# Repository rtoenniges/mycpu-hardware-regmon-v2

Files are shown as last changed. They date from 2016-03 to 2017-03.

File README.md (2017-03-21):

# MyCPU_HDW_RegMonV2
A hardware expansion for for the [MyCPU](http://www.mycpu.eu/) from Dennis Kuschel to display the various CPU internal registers.

#### Attention: 
**This project especially the layouts are not yet finished and have _never been tested!_
So be careful if you connect this to your MyCPU!**

## Features
- Values display in Hex using an EPROM to convert Binary to 7-segment
- Hold CPU on a specific address using DIP-Switches
- You dont have to build the whole Monitor - Its split into 3x Driver and 2x Monitor modules

## Registers
- Accu
- X-Reg
- Y-Reg
- Stackpointer
- OP-Code
- ALU-Reg 1
- ALU-Reg 2
- ALU-OUT
- Sign-, Zero-, Carry-Flag
- Program Counter
- Addressregister

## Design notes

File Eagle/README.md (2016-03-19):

# Hardware (Drivers and Monitors)
The hardware is each splitted into two modules (Driver and Monitor).
The two modules where connected by a ribbon cable which should not be too long.

## Driver 1 (Program Counter) -> Monitor 12
Driver 1 is for the Program Counter and have to be placed between the Signal Decoder- and the Program Counter-Board.

You have to remove IC44 and IC46 from the Program-Counter-Board and place it on the Driver 1-Board and use IC socket extensions to connect the ICs again to the Programm Counter-Board like the Memory-Base-, and the Memory-Extension-Board.

You can connect the Monitor 12-Board to display the Programm Counter value.

## Driver 2 (Address Bus) -> Monitor 12, AddressHold
Driver 2 is for the Address Bus and have to be placed between the Program Counter- and the Bus Interface-Board

You can connect the Monitor 12-Board to display the Address Bus value and with the AddressHold-Board you can select an address with dip-switches to hold the CPU on a specific point.

## Driver 3 (Accu, X, Y, SP, OP, AR1, AR2, ALU, O-, V-, C-Flag) -> Monitor 3
Driver 3 is for the various internal CPU register and have to be placed between the Microcode Control- and the Signal Decoder-Board.

You can connect the Monitor 3-Board to display all the registers and flags.

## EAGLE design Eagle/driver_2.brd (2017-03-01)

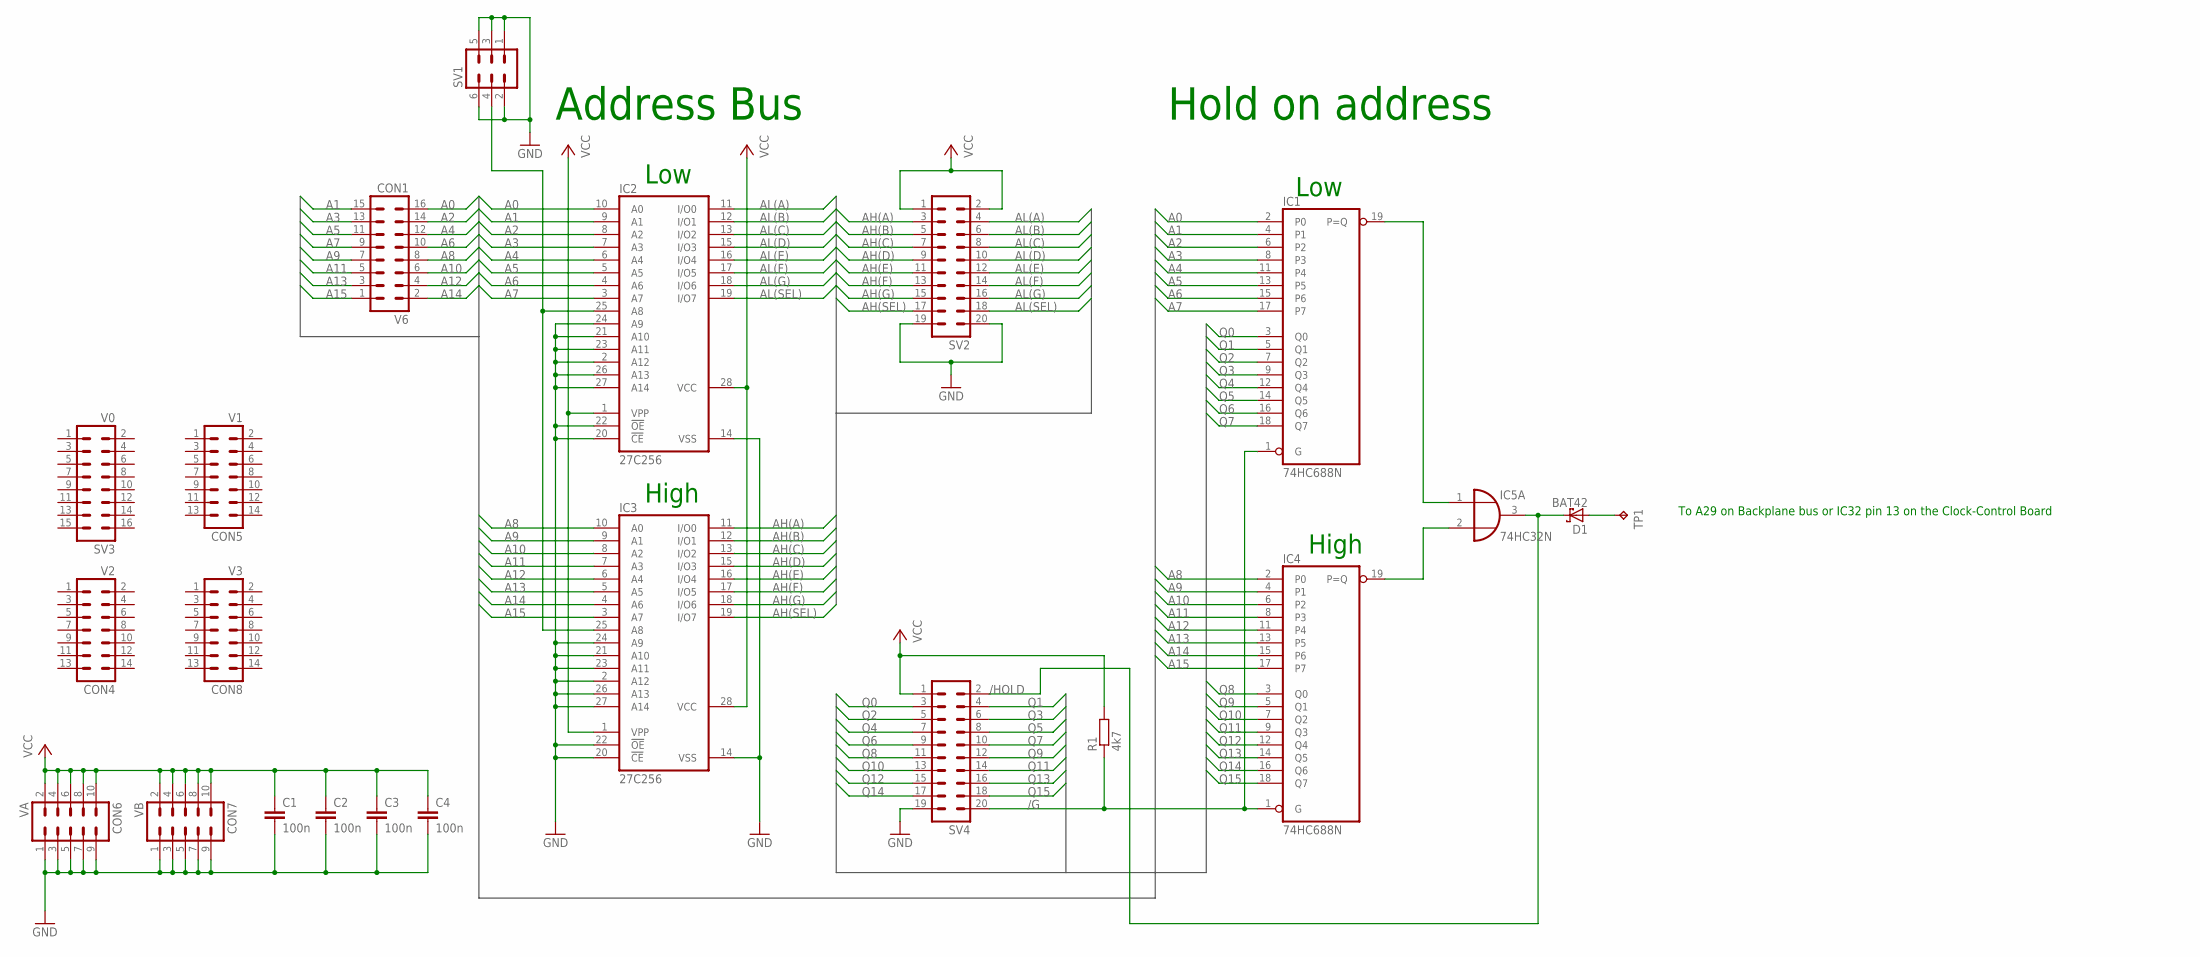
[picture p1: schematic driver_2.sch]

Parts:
C1, C2, C3, C4: 100n; C050-024X044
CON1: V6; ML16
CON4: V2; ML14
CON5: V1; ML14
CON6: VA; ML10
CON7: VB; ML10
CON8: V3; ML14
D1: BAT42; DO35-10
IC1, IC4: 74HC688N; DIL20
IC2, IC3: 27C256; DIL28-6
IC5: 74HC32N; DIL14
R1: 4k7; 0204/5
SV1: ML6
SV2, SV4: ML20L
SV3: V0; ML16
TP1: Interface -> R12; P1-17

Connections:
/G: IC1.1 (G), IC4.1 (G), R1.1, SV4.20
/HOLD: D1.C, IC5.3 (O), SV4.2
A0: CON1.16, IC1.2 (P0), IC2.10 (A0)
A1: CON1.15, IC1.4 (P1), IC2.9 (A1)
A2: CON1.14, IC1.6 (P2), IC2.8 (A2)
A3: CON1.13, IC1.8 (P3), IC2.7 (A3)
A4: CON1.12, IC1.11 (P4), IC2.6 (A4)
A5: CON1.11, IC1.13 (P5), IC2.5 (A5)
A6: CON1.10, IC1.15 (P6), IC2.4 (A6)
A7: CON1.9, IC1.17 (P7), IC2.3 (A7)
A8: CON1.8, IC3.10 (A0), IC4.2 (P0)
A9: CON1.7, IC3.9 (A1), IC4.4 (P1)
A10: CON1.6, IC3.8 (A2), IC4.6 (P2)
A11: CON1.5, IC3.7 (A3), IC4.8 (P3)
A12: CON1.4, IC3.6 (A4), IC4.11 (P4)
A13: CON1.3, IC3.5 (A5), IC4.13 (P5)
A14: CON1.2, IC3.4 (A6), IC4.15 (P6)
A15: CON1.1, IC3.3 (A7), IC4.17 (P7)
AH(A): IC3.11 (I/O0), SV2.3
AH(B): IC3.12 (I/O1), SV2.5
AH(C): IC3.13 (I/O2), SV2.7
AH(D): IC3.15 (I/O3), SV2.9
AH(E): IC3.16 (I/O4), SV2.11
AH(F): IC3.17 (I/O5), SV2.13
AH(G): IC3.18 (I/O6), SV2.15
AH(SEL): IC3.19 (I/O7), SV2.17
AL(A): IC2.11 (I/O0), SV2.4
AL(B): IC2.12 (I/O1), SV2.6
AL(C): IC2.13 (I/O2), SV2.8
AL(D): IC2.15 (I/O3), SV2.10
AL(E): IC2.16 (I/O4), SV2.12
AL(F): IC2.17 (I/O5), SV2.14
AL(G): IC2.18 (I/O6), SV2.16
AL(SEL): IC2.19 (I/O7), SV2.18
GND: C1.2, C2.2, C3.2, C4.2, CON6.1, CON6.3, CON6.5, CON6.7, CON6.9, CON7.1, CON7.3, CON7.5, CON7.7, CON7.9, IC1.10 (GND), IC2.2 (A12), IC2.14 (VSS), IC2.20 (!CE), IC2.21 (A10), IC2.22 (!OE), IC2.23 (A11), IC2.24 (A9), IC2.26 (A13), IC2.27 (A14), IC3.2 (A12), IC3.14 (VSS), IC3.20 (!CE), IC3.21 (A10), IC3.22 (!OE), IC3.23 (A11), IC3.24 (A9), IC3.26 (A13), IC3.27 (A14), IC4.10 (GND), IC5.7 (GND), SV1.1, SV1.2, SV1.3, SV1.5, SV1.6, SV2.19, SV2.20, SV4.19
unnamed: IC2.25 (A8), IC3.25 (A8), SV1.4
unnamed: IC1.19 (P=Q), IC5.1 (I0)
unnamed: IC4.19 (P=Q), IC5.2 (I1)
unnamed: D1.A, TP1.TP
Q0: IC1.3 (Q0), SV4.3
Q1: IC1.5 (Q1), SV4.4
Q2: IC1.7 (Q2), SV4.5
Q3: IC1.9 (Q3), SV4.6
Q4: IC1.12 (Q4), SV4.7
Q5: IC1.14 (Q5), SV4.8
Q6: IC1.16 (Q6), SV4.9
Q7: IC1.18 (Q7), SV4.10
Q8: IC4.3 (Q0), SV4.11
Q9: IC4.5 (Q1), SV4.12
Q10: IC4.7 (Q2), SV4.13
Q11: IC4.9 (Q3), SV4.14
Q12: IC4.12 (Q4), SV4.15
Q13: IC4.14 (Q5), SV4.16
Q14: IC4.16 (Q6), SV4.17
Q15: IC4.18 (Q7), SV4.18
VCC: C1.1, C2.1, C3.1, C4.1, CON6.2, CON6.4, CON6.6, CON6.8, CON6.10, CON7.2, CON7.4, CON7.6, CON7.8, CON7.10, IC1.20 (VCC), IC2.1 (VPP), IC2.28 (VCC), IC3.1 (VPP), IC3.28 (VCC), IC4.20 (VCC), IC5.14 (VCC), R1.2, SV2.1, SV2.2, SV4.1

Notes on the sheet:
Address Bus
Low
High
Hold on address
To A29 on Backplane bus or IC32 pin 13 on the Clock-Control Board

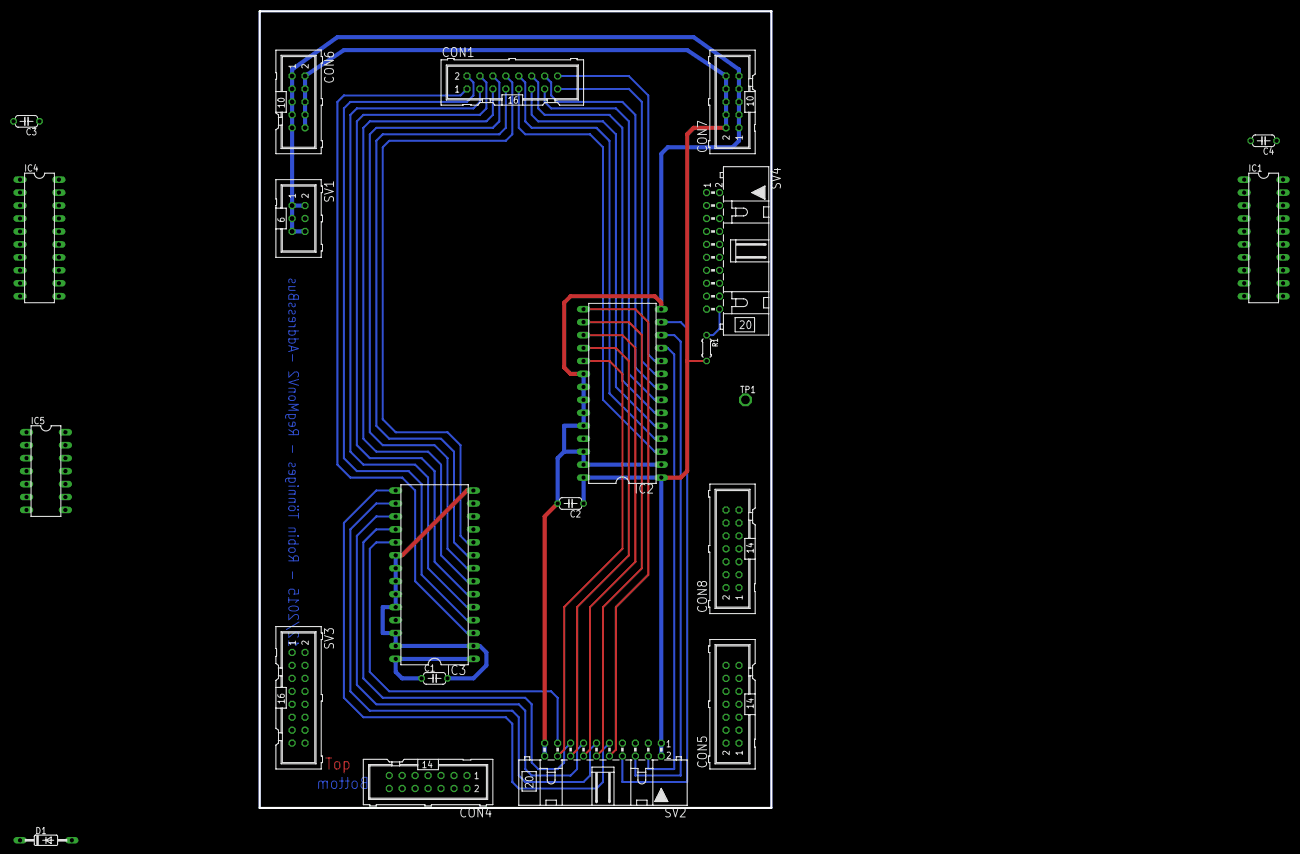
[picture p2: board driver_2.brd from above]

Board: 2 copper layers, 100.3 x 156.2 mm, 22 parts (0 on the bottom side), 56 nets.

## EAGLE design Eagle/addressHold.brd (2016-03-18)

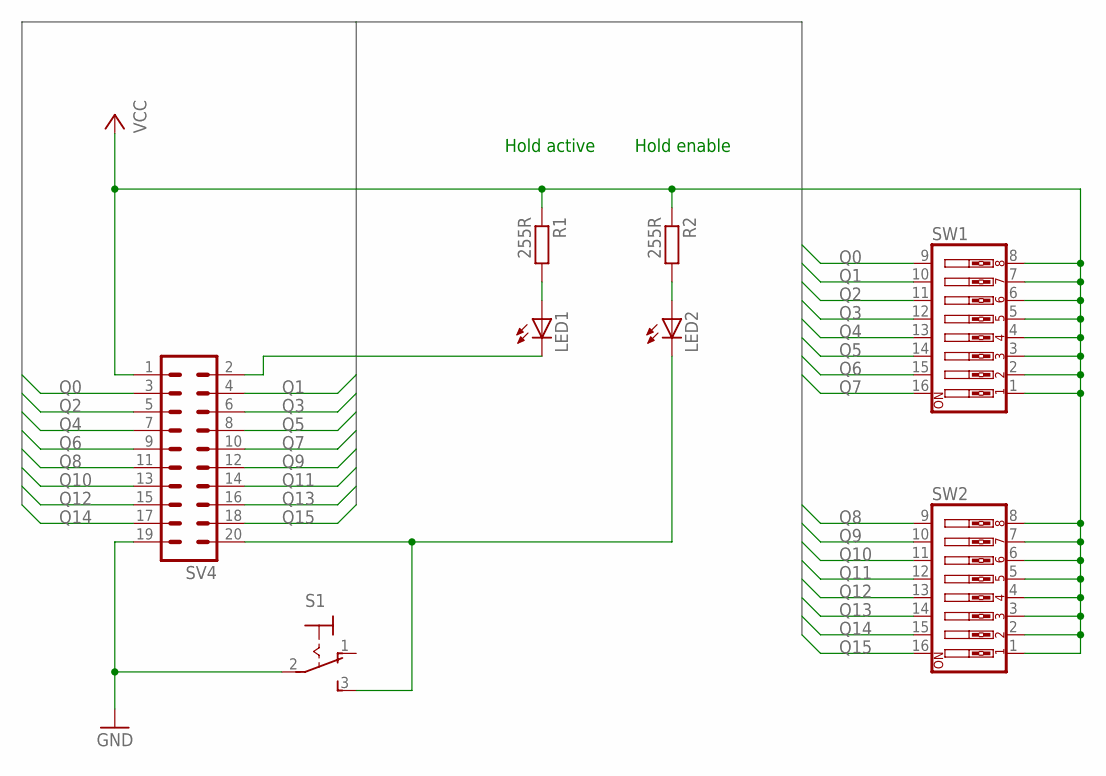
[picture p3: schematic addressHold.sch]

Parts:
LED1, LED2: LED5MM
R1, R2: 255R; 0204/5
S1: 320-916
SV4: ML20L
SW1, SW2: SW_DIP-8; EDG-08

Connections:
GND: S1.2, SV4.19
unnamed: LED2.K (C), S1.3 (S), SV4.20
unnamed: LED1.K (C), SV4.2
unnamed: LED1.A, R1.2
unnamed: LED2.A, R2.2
Q0: SV4.3, SW1.9
Q1: SV4.4, SW1.10
Q2: SV4.5, SW1.11
Q3: SV4.6, SW1.12
Q4: SV4.7, SW1.13
Q5: SV4.8, SW1.14
Q6: SV4.9, SW1.15
Q7: SV4.10, SW1.16
Q8: SV4.11, SW2.9
Q9: SV4.12, SW2.10
Q10: SV4.13, SW2.11
Q11: SV4.14, SW2.12
Q12: SV4.15, SW2.13
Q13: SV4.16, SW2.14
Q14: SV4.17, SW2.15
Q15: SV4.18, SW2.16
VCC: R1.1, R2.1, SV4.1, SW1.1, SW1.2, SW1.3, SW1.4, SW1.5, SW1.6, SW1.7, SW1.8, SW2.1, SW2.2, SW2.3, SW2.4, SW2.5, SW2.6, SW2.7, SW2.8

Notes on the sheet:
Hold enable
Hold active

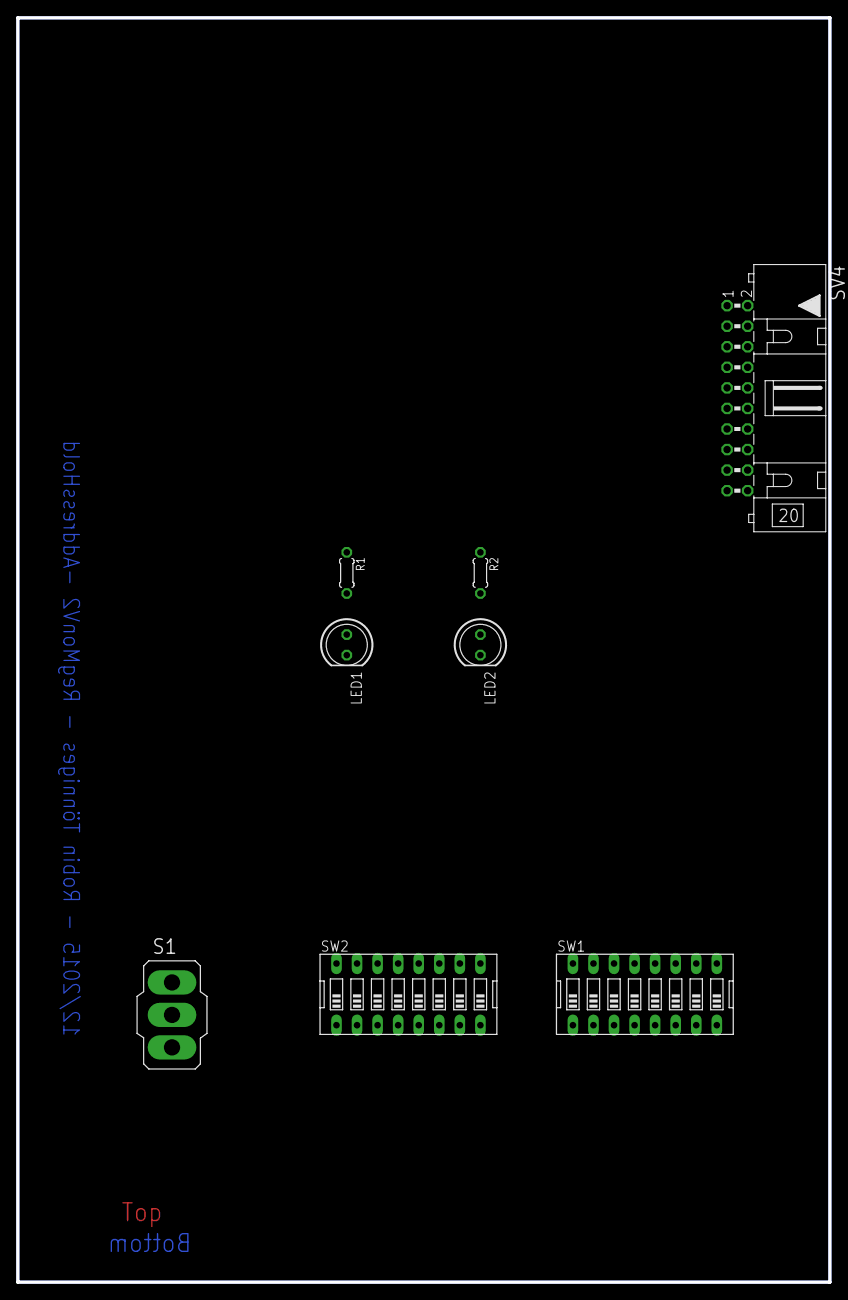
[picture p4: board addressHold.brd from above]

Board: 2 copper layers, 100.3 x 156.2 mm, 8 parts (0 on the bottom side), 22 nets.

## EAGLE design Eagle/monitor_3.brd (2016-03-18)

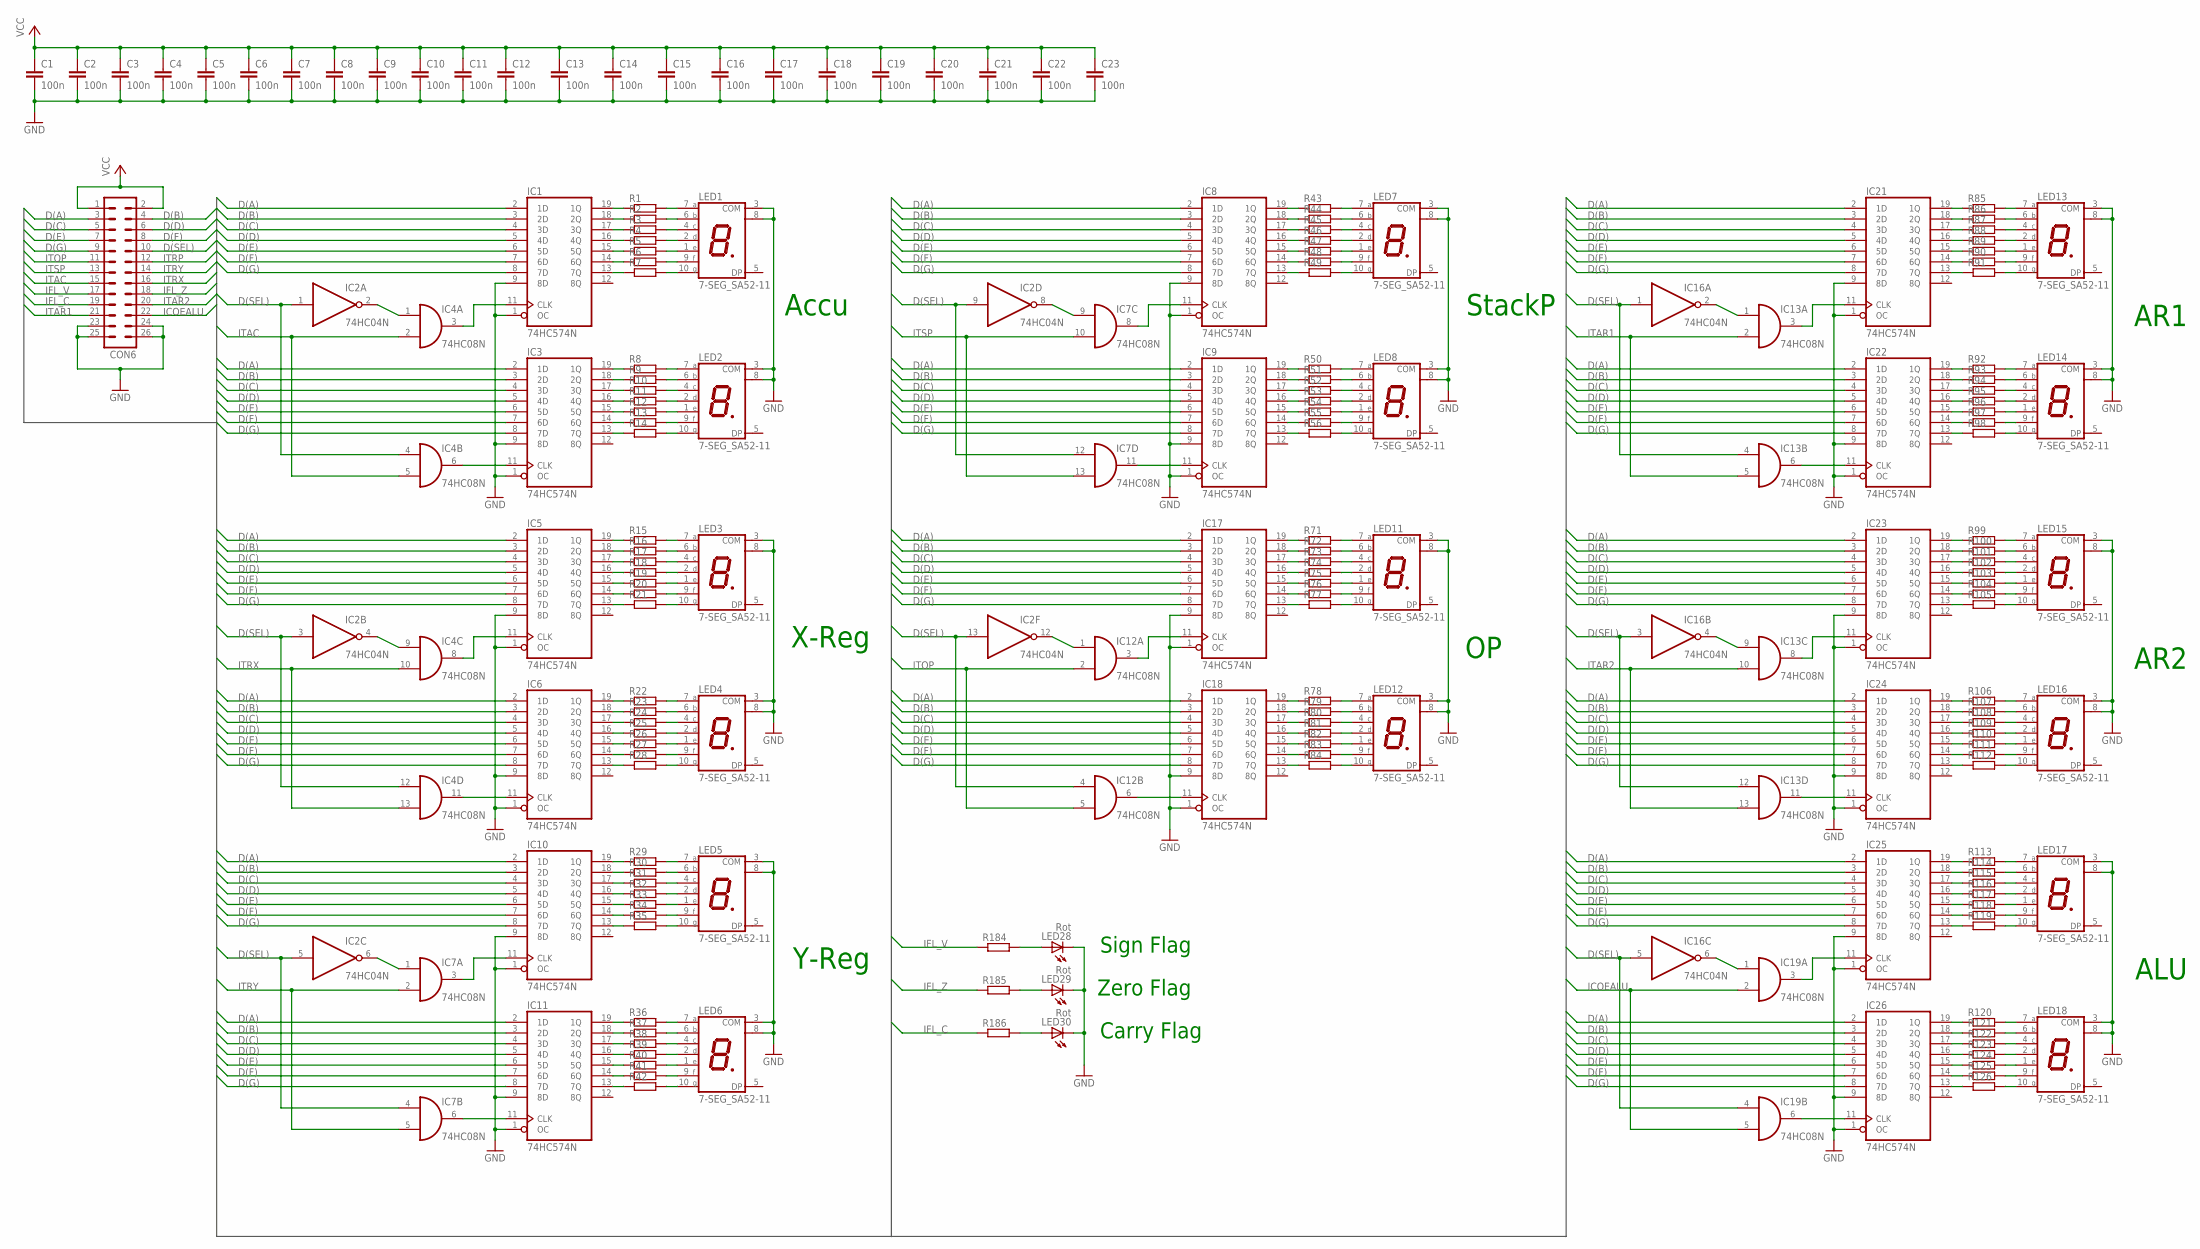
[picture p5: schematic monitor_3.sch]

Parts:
C1, C2, C3, C4, C5, C6, C7, C8, C9, C10, C11, C12, C13, C14, C15, C16, C17, C18, C19, C20, C21, C22, C23: 100n; C025-024X044
CON6: ML26L
IC1, IC3, IC5, IC6, IC8, IC9, IC10, IC11, IC17, IC18, IC21, IC22, IC23, IC24, IC25, IC26: 74HC574N; DIL20
IC2, IC16: 74HC04N; DIL14
IC4, IC7, IC12, IC13, IC19: 74HC08N; DIL14
LED1, LED2, LED3, LED4, LED5, LED6, LED7, LED8, LED11, LED12, LED13, LED14, LED15, LED16, LED17, LED18: 7-SEG_SA52-11; SA52-11
LED28, LED29, LED30: Rot; LED5MM
R1, R2, R3, R4, R5, R6, R7, R8, R9, R10, R11, R12, R13, R14, R15, R16, R17, R18, R19, R20, R21, R22, R23, R24, R25, R26, R27, R28, R29, R30, R31, R32, R33, R34, R35, R36, R37, R38, R39, R40, R41, R42, R43, R44, R45, R46, R47, R48, R49, R50, R51, R52, R53, R54, R55, R56, R71, R72, R73, R74, R75, R76, R77, R78, R79, R80, R81, R82, R83, R84, R85, R86, R87, R88, R89, R90, R91, R92, R93, R94, R95, R96, R97, R98, R99, R100, R101, R102, R103, R104, R105, R106, R107, R108, R109, R110, R111, R112, R113, R114, R115, R116, R117, R118, R119, R120, R121, R122, R123, R124, R125, R126, R184, R185, R186: R-EU_0207/7; 0207/7

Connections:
D(A): CON6.3, IC1.2 (1D), IC3.2 (1D), IC5.2 (1D), IC6.2 (1D), IC8.2 (1D), IC9.2 (1D), IC10.2 (1D), IC11.2 (1D), IC17.2 (1D), IC18.2 (1D), IC21.2 (1D), IC22.2 (1D), IC23.2 (1D), IC24.2 (1D), IC25.2 (1D), IC26.2 (1D)
D(B): CON6.4, IC1.3 (2D), IC3.3 (2D), IC5.3 (2D), IC6.3 (2D), IC8.3 (2D), IC9.3 (2D), IC10.3 (2D), IC11.3 (2D), IC17.3 (2D), IC18.3 (2D), IC21.3 (2D), IC22.3 (2D), IC23.3 (2D), IC24.3 (2D), IC25.3 (2D), IC26.3 (2D)
D(C): CON6.5, IC1.4 (3D), IC3.4 (3D), IC5.4 (3D), IC6.4 (3D), IC8.4 (3D), IC9.4 (3D), IC10.4 (3D), IC11.4 (3D), IC17.4 (3D), IC18.4 (3D), IC21.4 (3D), IC22.4 (3D), IC23.4 (3D), IC24.4 (3D), IC25.4 (3D), IC26.4 (3D)
D(D): CON6.6, IC1.5 (4D), IC3.5 (4D), IC5.5 (4D), IC6.5 (4D), IC8.5 (4D), IC9.5 (4D), IC10.5 (4D), IC11.5 (4D), IC17.5 (4D), IC18.5 (4D), IC21.5 (4D), IC22.5 (4D), IC23.5 (4D), IC24.5 (4D), IC25.5 (4D), IC26.5 (4D)
D(E): CON6.7, IC1.6 (5D), IC3.6 (5D), IC5.6 (5D), IC6.6 (5D), IC8.6 (5D), IC9.6 (5D), IC10.6 (5D), IC11.6 (5D), IC17.6 (5D), IC18.6 (5D), IC21.6 (5D), IC22.6 (5D), IC23.6 (5D), IC24.6 (5D), IC25.6 (5D), IC26.6 (5D)
D(F): CON6.8, IC1.7 (6D), IC3.7 (6D), IC5.7 (6D), IC6.7 (6D), IC8.7 (6D), IC9.7 (6D), IC10.7 (6D), IC11.7 (6D), IC17.7 (6D), IC18.7 (6D), IC21.7 (6D), IC22.7 (6D), IC23.7 (6D), IC24.7 (6D), IC25.7 (6D), IC26.7 (6D)
D(G): CON6.9, IC1.8 (7D), IC3.8 (7D), IC5.8 (7D), IC6.8 (7D), IC8.8 (7D), IC9.8 (7D), IC10.8 (7D), IC11.8 (7D), IC17.8 (7D), IC18.8 (7D), IC21.8 (7D), IC22.8 (7D), IC23.8 (7D), IC24.8 (7D), IC25.8 (7D), IC26.8 (7D)
D(SEL): CON6.10, IC2.1 (I), IC2.3 (I), IC2.5 (I), IC2.9 (I), IC2.13 (I), IC4.4 (I0), IC4.12 (I0), IC7.4 (I0), IC7.12 (I0), IC12.4 (I0), IC13.4 (I0), IC13.12 (I0), IC16.1 (I), IC16.3 (I), IC16.5 (I), IC19.4 (I0)
GND: C1.2, C2.2, C3.2, C4.2, C5.2, C6.2, C7.2, C8.2, C9.2, C10.2, C11.2, C12.2, C13.2, C14.2, C15.2, C16.2, C17.2, C18.2, C19.2, C20.2, C21.2, C22.2, C23.2, CON6.23, CON6.24, CON6.25, CON6.26, IC1.1 (OC), IC1.9 (8D), IC1.10 (GND), IC2.7 (GND), IC3.1 (OC), IC3.9 (8D), IC3.10 (GND), IC4.7 (GND), IC5.1 (OC), IC5.9 (8D), IC5.10 (GND), IC6.1 (OC), IC6.9 (8D), IC6.10 (GND), IC7.7 (GND), IC8.1 (OC), IC8.9 (8D), IC8.10 (GND), IC9.1 (OC), IC9.9 (8D), IC9.10 (GND), IC10.1 (OC), IC10.9 (8D), IC10.10 (GND), IC11.1 (OC), IC11.9 (8D), IC11.10 (GND), IC12.7 (GND), IC13.7 (GND), IC16.7 (GND), IC17.1 (OC), IC17.9 (8D), IC17.10 (GND), IC18.1 (OC), IC18.9 (8D), IC18.10 (GND), IC19.7 (GND), IC21.1 (OC), IC21.9 (8D), IC21.10 (GND), IC22.1 (OC), IC22.9 (8D), IC22.10 (GND), IC23.1 (OC), IC23.9 (8D), IC23.10 (GND), IC24.1 (OC), IC24.9 (8D), IC24.10 (GND), IC25.1 (OC), IC25.9 (8D), IC25.10 (GND), IC26.1 (OC), IC26.9 (8D), IC26.10 (GND), LED1.3 (COM), LED1.8 (COM), LED2.3 (COM), LED2.8 (COM), LED3.3 (COM), LED3.8 (COM), LED4.3 (COM), LED4.8 (COM), LED5.3 (COM), LED5.8 (COM), LED6.3 (COM), LED6.8 (COM), LED7.3 (COM), LED7.8 (COM), LED8.3 (COM), LED8.8 (COM), LED11.3 (COM), LED11.8 (COM), LED12.3 (COM), LED12.8 (COM), LED13.3 (COM), LED13.8 (COM), LED14.3 (COM), LED14.8 (COM), LED15.3 (COM), LED15.8 (COM), LED16.3 (COM), LED16.8 (COM), LED17.3 (COM), LED17.8 (COM), LED18.3 (COM), LED18.8 (COM), LED28.K (C), LED29.K (C), LED30.K (C)
ICOEALU: CON6.22, IC19.2 (I1), IC19.5 (I1)
IFL_C: CON6.19, R186.1
IFL_V: CON6.17, R184.1
IFL_Z: CON6.18, R185.1
ITAC: CON6.15, IC4.2 (I1), IC4.5 (I1)
ITAR1: CON6.21, IC13.2 (I1), IC13.5 (I1)
ITAR2: CON6.20, IC13.10 (I1), IC13.13 (I1)
ITOP: CON6.11, IC12.2 (I1), IC12.5 (I1)
ITRP: CON6.12
ITRX: CON6.16, IC4.10 (I1), IC4.13 (I1)
ITRY: CON6.14, IC7.2 (I1), IC7.5 (I1)
ITSP: CON6.13, IC7.10 (I1), IC7.13 (I1)
unnamed: IC2.2 (O), IC4.1 (I0)
unnamed: IC1.11 (CLK), IC4.3 (O)
unnamed: LED1.6 (B), R2.2
unnamed: IC1.19 (1Q), R1.1
unnamed: IC1.18 (2Q), R2.1
unnamed: IC1.17 (3Q), R3.1
unnamed: IC1.16 (4Q), R4.1
unnamed: IC1.15 (5Q), R5.1
unnamed: IC1.14 (6Q), R6.1
unnamed: IC1.13 (7Q), R7.1
unnamed: LED1.7 (A), R1.2
unnamed: LED1.4 (C), R3.2
unnamed: LED1.2 (D), R4.2
unnamed: LED1.1 (E), R5.2
unnamed: LED1.9 (F), R6.2
unnamed: LED1.10 (G), R7.2
unnamed: IC3.11 (CLK), IC4.6 (O)
unnamed: LED2.6 (B), R9.2
unnamed: IC3.19 (1Q), R8.1
unnamed: IC3.18 (2Q), R9.1
unnamed: IC3.17 (3Q), R10.1
unnamed: IC3.16 (4Q), R11.1
unnamed: IC3.15 (5Q), R12.1
unnamed: IC3.14 (6Q), R13.1
unnamed: IC3.13 (7Q), R14.1
unnamed: LED2.7 (A), R8.2
unnamed: LED2.4 (C), R10.2
unnamed: LED2.2 (D), R11.2
unnamed: LED2.1 (E), R12.2
unnamed: LED2.9 (F), R13.2
unnamed: LED2.10 (G), R14.2
unnamed: IC2.4 (O), IC4.9 (I0)
unnamed: IC4.8 (O), IC5.11 (CLK)
unnamed: IC4.11 (O), IC6.11 (CLK)
unnamed: LED3.6 (B), R16.2
unnamed: IC5.19 (1Q), R15.1
unnamed: IC5.18 (2Q), R16.1
unnamed: IC5.17 (3Q), R17.1
unnamed: IC5.16 (4Q), R18.1
unnamed: IC5.15 (5Q), R19.1
unnamed: IC5.14 (6Q), R20.1
unnamed: IC5.13 (7Q), R21.1
unnamed: LED3.7 (A), R15.2
unnamed: LED3.4 (C), R17.2
unnamed: LED3.2 (D), R18.2
unnamed: LED3.1 (E), R19.2
unnamed: LED3.9 (F), R20.2
unnamed: LED3.10 (G), R21.2
unnamed: IC2.6 (O), IC7.1 (I0)
unnamed: IC7.3 (O), IC10.11 (CLK)
unnamed: IC7.6 (O), IC11.11 (CLK)
unnamed: LED7.6 (B), R44.2
unnamed: IC8.19 (1Q), R43.1
unnamed: IC8.18 (2Q), R44.1
unnamed: IC8.17 (3Q), R45.1
unnamed: IC8.16 (4Q), R46.1
unnamed: IC8.15 (5Q), R47.1
unnamed: IC8.14 (6Q), R48.1
unnamed: IC8.13 (7Q), R49.1
unnamed: LED7.7 (A), R43.2
unnamed: LED7.4 (C), R45.2
unnamed: LED7.2 (D), R46.2
unnamed: LED7.1 (E), R47.2
unnamed: LED7.9 (F), R48.2
unnamed: LED7.10 (G), R49.2
unnamed: IC2.8 (O), IC7.9 (I0)
unnamed: IC7.8 (O), IC8.11 (CLK)
unnamed: IC7.11 (O), IC9.11 (CLK)
unnamed: LED8.6 (B), R51.2
unnamed: IC9.19 (1Q), R50.1
unnamed: IC9.18 (2Q), R51.1
unnamed: IC9.17 (3Q), R52.1
unnamed: IC9.16 (4Q), R53.1
unnamed: IC9.15 (5Q), R54.1
unnamed: IC9.14 (6Q), R55.1
unnamed: IC9.13 (7Q), R56.1
unnamed: LED8.7 (A), R50.2
unnamed: LED8.4 (C), R52.2
unnamed: LED8.2 (D), R53.2
unnamed: LED8.1 (E), R54.2
unnamed: LED8.9 (F), R55.2
unnamed: LED8.10 (G), R56.2
unnamed: IC2.12 (O), IC12.1 (I0)
unnamed: IC12.3 (O), IC17.11 (CLK)
unnamed: IC12.6 (O), IC18.11 (CLK)
unnamed: LED13.6 (B), R86.2
unnamed: IC21.19 (1Q), R85.1
unnamed: IC21.18 (2Q), R86.1
unnamed: IC21.17 (3Q), R87.1
unnamed: IC21.16 (4Q), R88.1
unnamed: IC21.15 (5Q), R89.1
unnamed: IC21.14 (6Q), R90.1
unnamed: IC21.13 (7Q), R91.1
unnamed: LED13.7 (A), R85.2
unnamed: LED13.4 (C), R87.2
unnamed: LED13.2 (D), R88.2
unnamed: LED13.1 (E), R89.2
unnamed: LED13.9 (F), R90.2
unnamed: LED13.10 (G), R91.2
unnamed: IC13.1 (I0), IC16.2 (O)
unnamed: IC13.3 (O), IC21.11 (CLK)
unnamed: IC13.6 (O), IC22.11 (CLK)
unnamed: LED14.6 (B), R93.2
unnamed: IC22.19 (1Q), R92.1
unnamed: IC22.18 (2Q), R93.1
unnamed: IC22.17 (3Q), R94.1
unnamed: IC22.16 (4Q), R95.1
unnamed: IC22.15 (5Q), R96.1
unnamed: IC22.14 (6Q), R97.1
unnamed: IC22.13 (7Q), R98.1
unnamed: LED14.7 (A), R92.2
unnamed: LED14.4 (C), R94.2
unnamed: LED14.2 (D), R95.2
unnamed: LED14.1 (E), R96.2
unnamed: LED14.9 (F), R97.2
unnamed: LED14.10 (G), R98.2
unnamed: IC13.9 (I0), IC16.4 (O)
unnamed: IC13.8 (O), IC23.11 (CLK)
unnamed: IC13.11 (O), IC24.11 (CLK)
unnamed: LED15.6 (B), R100.2
unnamed: IC23.19 (1Q), R99.1
unnamed: IC23.18 (2Q), R100.1
unnamed: IC23.17 (3Q), R101.1
unnamed: IC23.16 (4Q), R102.1
unnamed: IC23.15 (5Q), R103.1
unnamed: IC23.14 (6Q), R104.1
unnamed: IC23.13 (7Q), R105.1
unnamed: LED15.7 (A), R99.2
unnamed: LED15.4 (C), R101.2
unnamed: LED15.2 (D), R102.2
unnamed: LED15.1 (E), R103.2
unnamed: LED15.9 (F), R104.2
unnamed: LED15.10 (G), R105.2
unnamed: IC16.6 (O), IC19.1 (I0)
unnamed: IC19.3 (O), IC25.11 (CLK)
unnamed: IC19.6 (O), IC26.11 (CLK)
unnamed: LED4.6 (B), R23.2
unnamed: IC6.19 (1Q), R22.1
unnamed: IC6.18 (2Q), R23.1
unnamed: IC6.17 (3Q), R24.1
unnamed: IC6.16 (4Q), R25.1
unnamed: IC6.15 (5Q), R26.1
unnamed: IC6.14 (6Q), R27.1
unnamed: IC6.13 (7Q), R28.1
unnamed: LED4.7 (A), R22.2
unnamed: LED4.4 (C), R24.2
unnamed: LED4.2 (D), R25.2
unnamed: LED4.1 (E), R26.2
unnamed: LED4.9 (F), R27.2
unnamed: LED4.10 (G), R28.2
unnamed: LED5.6 (B), R30.2
unnamed: IC10.19 (1Q), R29.1
unnamed: IC10.18 (2Q), R30.1
unnamed: IC10.17 (3Q), R31.1
unnamed: IC10.16 (4Q), R32.1
unnamed: IC10.15 (5Q), R33.1
unnamed: IC10.14 (6Q), R34.1
unnamed: IC10.13 (7Q), R35.1
unnamed: LED5.7 (A), R29.2
unnamed: LED5.4 (C), R31.2
unnamed: LED5.2 (D), R32.2
unnamed: LED5.1 (E), R33.2
unnamed: LED5.9 (F), R34.2
unnamed: LED5.10 (G), R35.2
unnamed: LED6.6 (B), R37.2
unnamed: IC11.19 (1Q), R36.1
unnamed: IC11.18 (2Q), R37.1
unnamed: IC11.17 (3Q), R38.1
unnamed: IC11.16 (4Q), R39.1
unnamed: IC11.15 (5Q), R40.1
unnamed: IC11.14 (6Q), R41.1
unnamed: IC11.13 (7Q), R42.1
unnamed: LED6.7 (A), R36.2
unnamed: LED6.4 (C), R38.2
unnamed: LED6.2 (D), R39.2
unnamed: LED6.1 (E), R40.2
unnamed: LED6.9 (F), R41.2
unnamed: LED6.10 (G), R42.2
unnamed: LED11.6 (B), R72.2
unnamed: IC17.19 (1Q), R71.1
unnamed: IC17.18 (2Q), R72.1
unnamed: IC17.17 (3Q), R73.1
unnamed: IC17.16 (4Q), R74.1
unnamed: IC17.15 (5Q), R75.1
unnamed: IC17.14 (6Q), R76.1
unnamed: IC17.13 (7Q), R77.1
unnamed: LED11.7 (A), R71.2
unnamed: LED11.4 (C), R73.2
unnamed: LED11.2 (D), R74.2
unnamed: LED11.1 (E), R75.2
unnamed: LED11.9 (F), R76.2
unnamed: LED11.10 (G), R77.2
unnamed: LED12.6 (B), R79.2
unnamed: IC18.19 (1Q), R78.1
unnamed: IC18.18 (2Q), R79.1
unnamed: IC18.17 (3Q), R80.1
unnamed: IC18.16 (4Q), R81.1
unnamed: IC18.15 (5Q), R82.1
unnamed: IC18.14 (6Q), R83.1
unnamed: IC18.13 (7Q), R84.1
unnamed: LED12.7 (A), R78.2
unnamed: LED12.4 (C), R80.2
unnamed: LED12.2 (D), R81.2
unnamed: LED12.1 (E), R82.2
unnamed: LED12.9 (F), R83.2
unnamed: LED12.10 (G), R84.2
unnamed: LED16.6 (B), R107.2
unnamed: IC24.19 (1Q), R106.1
unnamed: IC24.18 (2Q), R107.1
unnamed: IC24.17 (3Q), R108.1
unnamed: IC24.16 (4Q), R109.1
unnamed: IC24.15 (5Q), R110.1
unnamed: IC24.14 (6Q), R111.1
unnamed: IC24.13 (7Q), R112.1
unnamed: LED16.7 (A), R106.2
unnamed: LED16.4 (C), R108.2
unnamed: LED16.2 (D), R109.2
unnamed: LED16.1 (E), R110.2
unnamed: LED16.9 (F), R111.2
unnamed: LED16.10 (G), R112.2
unnamed: LED17.6 (B), R114.2
unnamed: IC25.19 (1Q), R113.1
unnamed: IC25.18 (2Q), R114.1
unnamed: IC25.17 (3Q), R115.1
unnamed: IC25.16 (4Q), R116.1
unnamed: IC25.15 (5Q), R117.1
unnamed: IC25.14 (6Q), R118.1
unnamed: IC25.13 (7Q), R119.1
unnamed: LED17.7 (A), R113.2
unnamed: LED17.4 (C), R115.2
unnamed: LED17.2 (D), R116.2
unnamed: LED17.1 (E), R117.2
unnamed: LED17.9 (F), R118.2
unnamed: LED17.10 (G), R119.2
unnamed: LED18.6 (B), R121.2
unnamed: IC26.19 (1Q), R120.1
unnamed: IC26.18 (2Q), R121.1
unnamed: IC26.17 (3Q), R122.1
unnamed: IC26.16 (4Q), R123.1
unnamed: IC26.15 (5Q), R124.1
unnamed: IC26.14 (6Q), R125.1
unnamed: IC26.13 (7Q), R126.1
unnamed: LED18.7 (A), R120.2
unnamed: LED18.4 (C), R122.2
unnamed: LED18.2 (D), R123.2
unnamed: LED18.1 (E), R124.2
unnamed: LED18.9 (F), R125.2
unnamed: LED18.10 (G), R126.2
unnamed: LED28.A, R184.2
unnamed: LED29.A, R185.2
unnamed: LED30.A, R186.2
VCC: C1.1, C2.1, C3.1, C4.1, C5.1, C6.1, C7.1, C8.1, C9.1, C10.1, C11.1, C12.1, C13.1, C14.1, C15.1, C16.1, C17.1, C18.1, C19.1, C20.1, C21.1, C22.1, C23.1, CON6.1, CON6.2, IC1.20 (VCC), IC2.14 (VCC), IC3.20 (VCC), IC4.14 (VCC), IC5.20 (VCC), IC6.20 (VCC), IC7.14 (VCC), IC8.20 (VCC), IC9.20 (VCC), IC10.20 (VCC), IC11.20 (VCC), IC12.14 (VCC), IC13.14 (VCC), IC16.14 (VCC), IC17.20 (VCC), IC18.20 (VCC), IC19.14 (VCC), IC21.20 (VCC), IC22.20 (VCC), IC23.20 (VCC), IC24.20 (VCC), IC25.20 (VCC), IC26.20 (VCC)

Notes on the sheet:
Accu
X-Reg
Y-Reg
StackP
AR1
AR2
ALU
Sign Flag
Zero Flag
Carry Flag

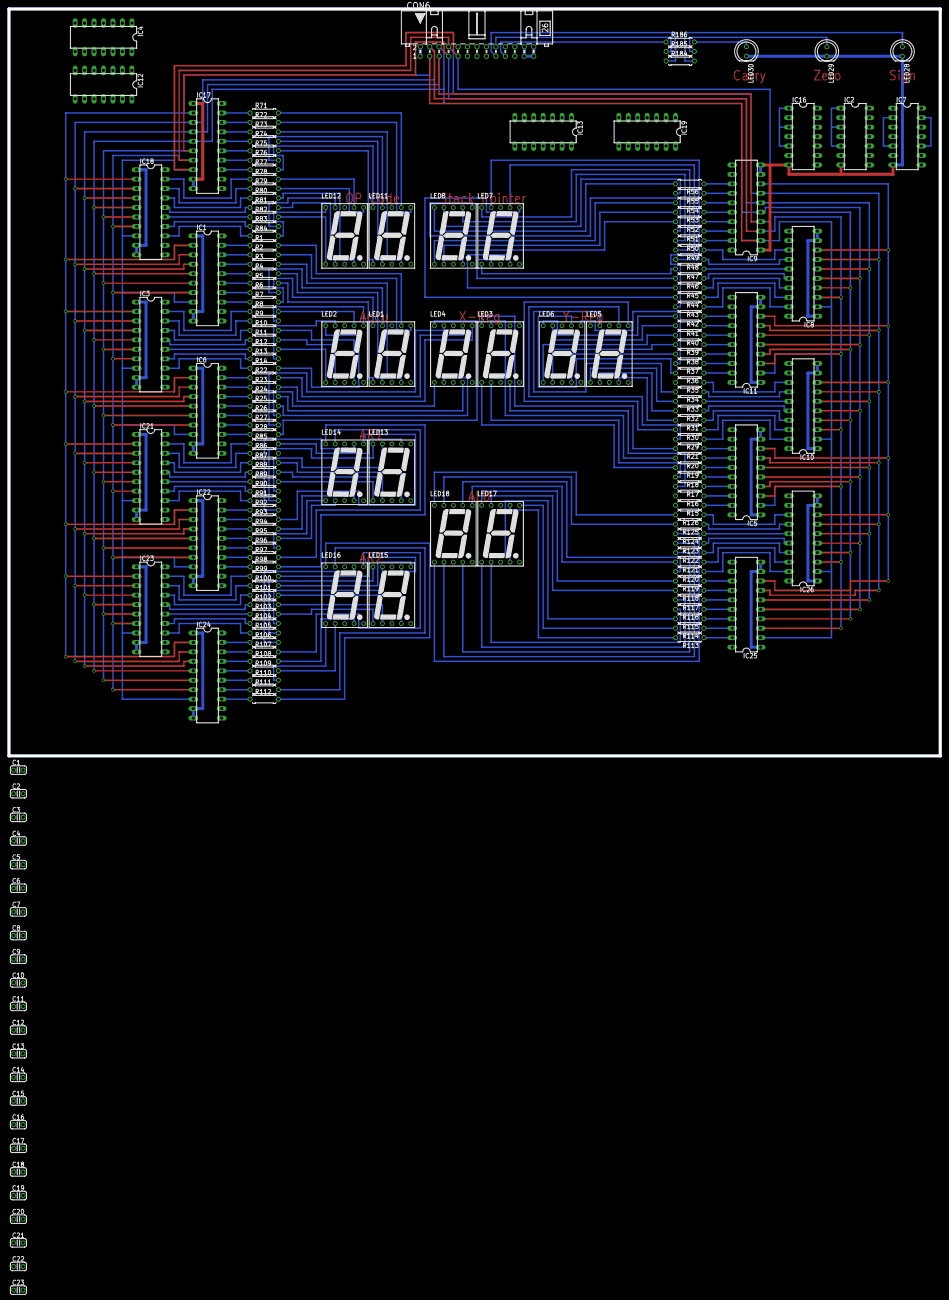
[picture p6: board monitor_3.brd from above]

Board: 2 copper layers, 250.2 x 200.7 mm, 181 parts (0 on the bottom side), 272 nets.

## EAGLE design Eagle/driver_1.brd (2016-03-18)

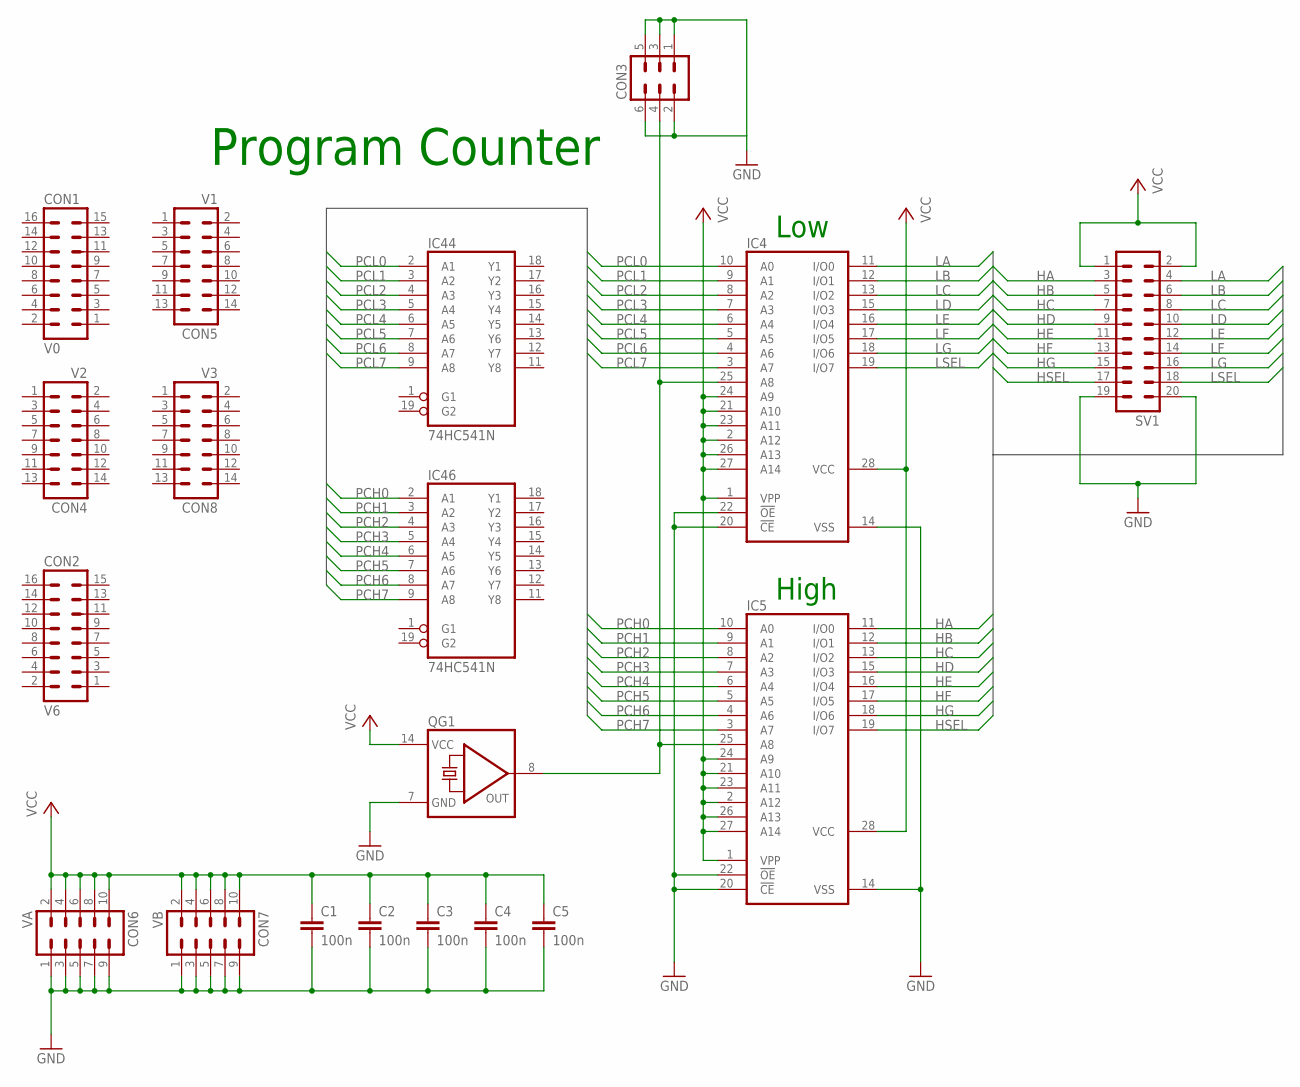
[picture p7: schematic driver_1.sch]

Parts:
C1, C2, C3, C4, C5: 100n; C050-024X044
CON1: V0; ML16
CON2: V6; ML16
CON3: ML6
CON4: V2; ML14
CON5: V1; ML14
CON6: VA; ML10
CON7: VB; ML10
CON8: V3; ML14
IC4, IC5: 27C256AG; DIL28-6
IC44, IC46: 74HC541N; DIL20
QG1: QG5860; DIL14S
SV1: ML20L

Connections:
GND: C1.2, C2.2, C3.2, C4.2, C5.2, CON3.1, CON3.2, CON3.3, CON3.5, CON3.6, CON6.1, CON6.3, CON6.5, CON6.7, CON6.9, CON7.1, CON7.3, CON7.5, CON7.7, CON7.9, IC4.14 (VSS), IC4.20 (!CE), IC4.22 (!OE), IC5.14 (VSS), IC5.20 (!CE), IC5.22 (!OE), IC44.10 (GND), IC46.10 (GND), QG1.7 (GND), SV1.19, SV1.20
HA: IC5.11 (I/O0), SV1.3
HB: IC5.12 (I/O1), SV1.5
HC: IC5.13 (I/O2), SV1.7
HD: IC5.15 (I/O3), SV1.9
HE: IC5.16 (I/O4), SV1.11
HF: IC5.17 (I/O5), SV1.13
HG: IC5.18 (I/O6), SV1.15
HSEL: IC5.19 (I/O7), SV1.17
LA: IC4.11 (I/O0), SV1.4
LB: IC4.12 (I/O1), SV1.6
LC: IC4.13 (I/O2), SV1.8
LD: IC4.15 (I/O3), SV1.10
LE: IC4.16 (I/O4), SV1.12
LF: IC4.17 (I/O5), SV1.14
LG: IC4.18 (I/O6), SV1.16
LSEL: IC4.19 (I/O7), SV1.18
unnamed: CON3.4, IC4.25 (A8), IC5.25 (A8), QG1.8 (OUT)
PCH0: IC5.10 (A0), IC46.2 (A1)
PCH1: IC5.9 (A1), IC46.3 (A2)
PCH2: IC5.8 (A2), IC46.4 (A3)
PCH3: IC5.7 (A3), IC46.5 (A4)
PCH4: IC5.6 (A4), IC46.6 (A5)
PCH5: IC5.5 (A5), IC46.7 (A6)
PCH6: IC5.4 (A6), IC46.8 (A7)
PCH7: IC5.3 (A7), IC46.9 (A8)
PCL0: IC4.10 (A0), IC44.2 (A1)
PCL1: IC4.9 (A1), IC44.3 (A2)
PCL2: IC4.8 (A2), IC44.4 (A3)
PCL3: IC4.7 (A3), IC44.5 (A4)
PCL4: IC4.6 (A4), IC44.6 (A5)
PCL5: IC4.5 (A5), IC44.7 (A6)
PCL6: IC4.4 (A6), IC44.8 (A7)
PCL7: IC4.3 (A7), IC44.9 (A8)
VCC: C1.1, C2.1, C3.1, C4.1, C5.1, CON6.2, CON6.4, CON6.6, CON6.8, CON6.10, CON7.2, CON7.4, CON7.6, CON7.8, CON7.10, IC4.1 (VPP), IC4.2 (A12), IC4.21 (A10), IC4.23 (A11), IC4.24 (A9), IC4.26 (A13), IC4.27 (A14), IC4.28 (VCC), IC5.1 (VPP), IC5.2 (A12), IC5.21 (A10), IC5.23 (A11), IC5.24 (A9), IC5.26 (A13), IC5.27 (A14), IC5.28 (VCC), IC44.20 (VCC), IC46.20 (VCC), QG1.14 (VCC), SV1.1, SV1.2

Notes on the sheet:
Program Counter
Low
High

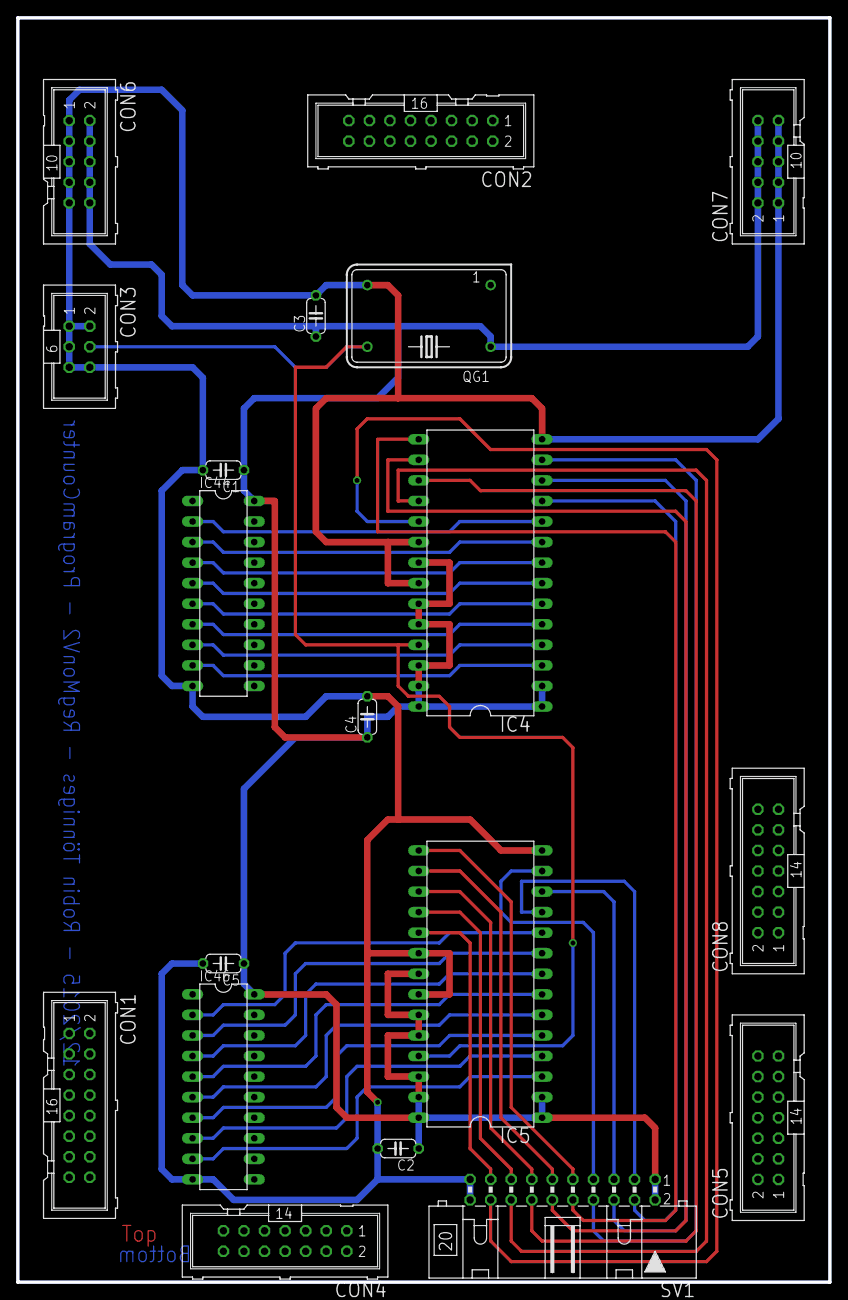
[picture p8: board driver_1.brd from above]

Board: 2 copper layers, 100.3 x 156.2 mm, 19 parts (0 on the bottom side), 35 nets.

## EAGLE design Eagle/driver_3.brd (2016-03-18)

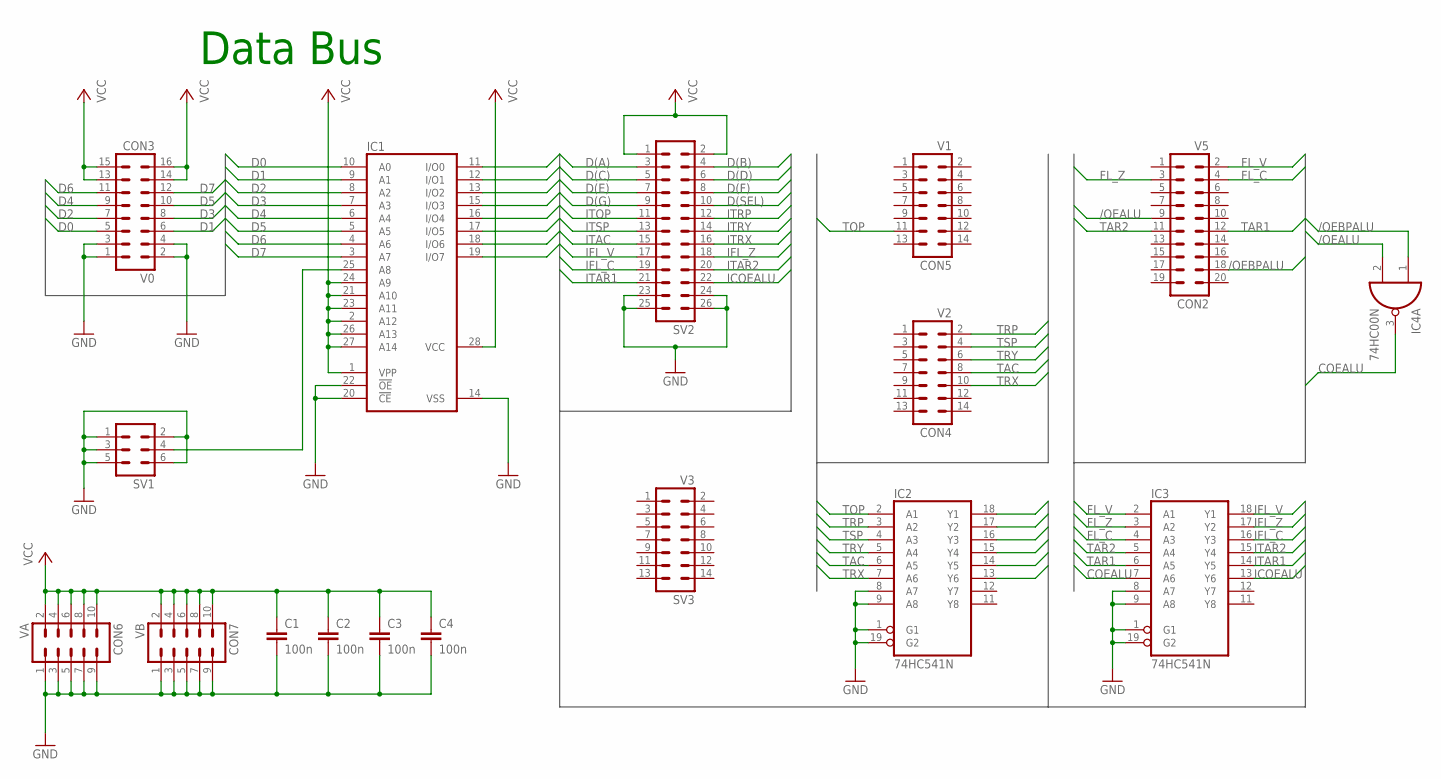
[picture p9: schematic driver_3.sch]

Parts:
C1, C2, C3, C4: 100n; C050-024X044
CON2: V5; ML20
CON3: V0; ML16
CON4: V2; ML14
CON5: V1; ML14
CON6: VA; ML10
CON7: VB; ML10
IC1: 27C256AG; DIL28-6
IC2, IC3: 74HC541N; DIL20
IC4: 74HC00N; DIL14
SV1: ML6
SV2: ML26L
SV3: V3; ML14

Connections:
/OEALU: CON2.9, IC4.2 (I1)
/OEBPALU: CON2.18, IC4.1 (I0)
COEALU: IC3.7 (A6), IC4.3 (O)
D0: CON3.5, IC1.10 (A0)
D1: CON3.6, IC1.9 (A1)
D2: CON3.7, IC1.8 (A2)
D3: CON3.8, IC1.7 (A3)
D4: CON3.9, IC1.6 (A4)
D5: CON3.10, IC1.5 (A5)
D6: CON3.11, IC1.4 (A6)
D7: CON3.12, IC1.3 (A7)
D(A): IC1.11 (I/O0), SV2.3
D(B): IC1.12 (I/O1), SV2.4
D(C): IC1.13 (I/O2), SV2.5
D(D): IC1.15 (I/O3), SV2.6
D(E): IC1.16 (I/O4), SV2.7
D(F): IC1.17 (I/O5), SV2.8
D(G): IC1.18 (I/O6), SV2.9
D(SEL): IC1.19 (I/O7), SV2.10
FL_C: CON2.4, IC3.4 (A3)
FL_V: CON2.2, IC3.2 (A1)
FL_Z: CON2.3, IC3.3 (A2)
GND: C1.2, C2.2, C3.2, C4.2, CON3.1, CON3.2, CON3.3, CON3.4, CON6.1, CON6.3, CON6.5, CON6.7, CON6.9, CON7.1, CON7.3, CON7.5, CON7.7, CON7.9, IC1.14 (VSS), IC1.20 (!CE), IC1.22 (!OE), IC2.1 (G1), IC2.8 (A7), IC2.9 (A8), IC2.10 (GND), IC2.19 (G2), IC3.1 (G1), IC3.8 (A7), IC3.9 (A8), IC3.10 (GND), IC3.19 (G2), IC4.7 (GND), SV1.1, SV1.2, SV1.3, SV1.5, SV1.6, SV2.23, SV2.24, SV2.25, SV2.26
ICOEALU: IC3.13 (Y6), SV2.22
IFL_C: IC3.16 (Y3), SV2.19
IFL_V: IC3.18 (Y1), SV2.17
IFL_Z: IC3.17 (Y2), SV2.18
ITAC: IC2.14 (Y5), SV2.15
ITAR1: IC3.14 (Y5), SV2.21
ITAR2: IC3.15 (Y4), SV2.20
ITOP: IC2.18 (Y1), SV2.11
ITRP: IC2.17 (Y2), SV2.12
ITRX: IC2.13 (Y6), SV2.16
ITRY: IC2.15 (Y4), SV2.14
ITSP: IC2.16 (Y3), SV2.13
unnamed: IC1.25 (A8), SV1.4
TAC: CON4.8, IC2.6 (A5)
TAR1: CON2.12, IC3.6 (A5)
TAR2: CON2.11, IC3.5 (A4)
TOP: CON5.11, IC2.2 (A1)
TRP: CON4.2, IC2.3 (A2)
TRX: CON4.10, IC2.7 (A6)
TRY: CON4.6, IC2.5 (A4)
TSP: CON4.4, IC2.4 (A3)
VCC: C1.1, C2.1, C3.1, C4.1, CON3.13, CON3.14, CON3.15, CON3.16, CON6.2, CON6.4, CON6.6, CON6.8, CON6.10, CON7.2, CON7.4, CON7.6, CON7.8, CON7.10, IC1.1 (VPP), IC1.2 (A12), IC1.21 (A10), IC1.23 (A11), IC1.24 (A9), IC1.26 (A13), IC1.27 (A14), IC1.28 (VCC), IC2.20 (VCC), IC3.20 (VCC), IC4.14 (VCC), SV2.1, SV2.2

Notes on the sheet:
Data Bus

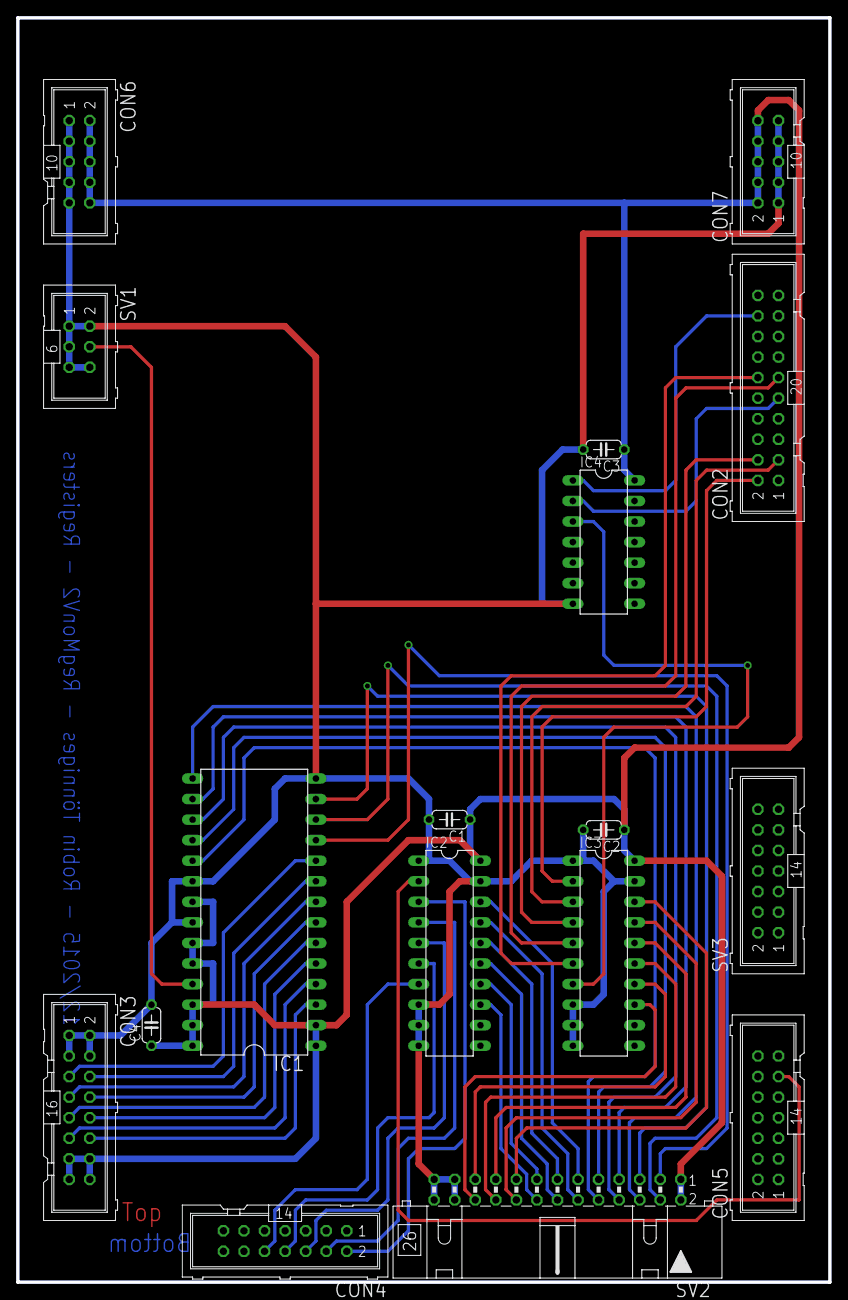
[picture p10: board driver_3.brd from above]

Board: 2 copper layers, 100.3 x 156.2 mm, 17 parts (0 on the bottom side), 45 nets.
